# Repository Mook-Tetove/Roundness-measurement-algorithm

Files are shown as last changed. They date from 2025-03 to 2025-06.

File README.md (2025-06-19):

# Roundness-measurement-algorithm
A roundness measurement algorithm program based on single-point laser traversal ranging (based on C language) 
一种基于单点激光遍历测距的圆度测量算法程序（基于C语言）包括软件和硬件模型的设计

这个程序是一个圆度测量系统，它使用激光测距仪和旋转机械臂来获取物体的内外径数据，并通过最小二乘法拟合出一个圆，计算出拟合圆的半径以及测量点的最大、最小半径。以下是该系统的详细说明：
## 系统组成
机械结构
可 360 度旋转的机械臂
固定在机械臂上的激光测距仪
旋转驱动电机（需支持精确角度控制）
##硬件接口
电机控制接口（如步进电机驱动器）
激光测距仪数据采集接口
微控制器或计算机平台运行本程序
##软件功能
控制电机完成 360 度旋转
在每个角度位置采集激光测距数据
计算内径数据
坐标转换与圆拟合算法
计算并输出圆度分析结果
电机控制与数据采集
目前程序中缺少电机控制和自动数据采集部分，以下是需要补充的关键功能：
##电机控制模块
初始化电机驱动器
设置旋转角度分辨率（例如每度一个测量点）
控制电机按指定角度步进旋转
提供角度位置反馈
数据采集流程
1. 初始化系统
2. 设置测量参数（臂长、测量点数等）
3. 将机械臂移动到起始位置
4. 循环360次（每次旋转1度）：
   a. 发送电机旋转命令
   b. 等待电机稳定
   c. 读取激光测距仪数据
   d. 存储当前角度和测量数据
5. 完成测量，回到起始位置
6. 进行数据处理和分析

##使用说明
系统连接
将激光测距仪连接到数据采集接口
将电机驱动器连接到控制接口
确保系统供电稳定
参数设置
修改程序中的测量参数（如测量点数、角度分辨率）
输入机械臂长度（程序中的Rceliangbi）
运行程序
编译并运行程序
程序会提示输入机械臂长度
程序将控制电机旋转并采集数据
最终输出拟合圆半径和测量点的最大 / 最小半径

##注意事项
程序中的 GPIO 引脚定义需要根据实际硬件连接进行修改
步进电机控制参数（如细分数、步进脉冲频率）需要根据实际电机和驱动器调整
激光测距仪数据读取函数需要根据实际设备接口协议实现
电机旋转时需要确保机械结构安全，避免碰撞
在实际应用中，可能需要增加滤波算法处理测量噪声
圆拟合算法中的数学公式可能需要根据具体应用场景调整
以上是该圆度测量系统的详细说明和改进建议。根据实际硬件平台和设备接口，你可能需要进一步修改代码以实现完整功能。

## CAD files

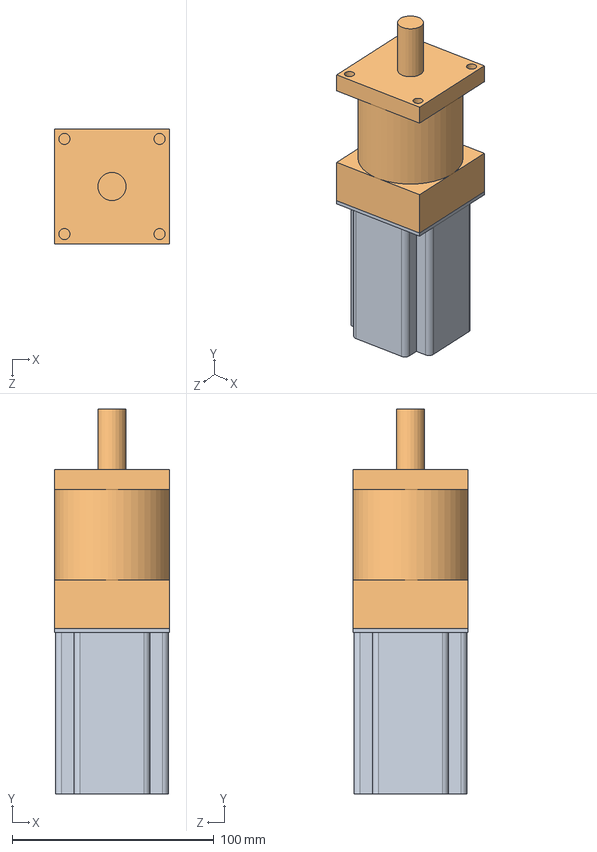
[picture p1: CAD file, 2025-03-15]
Roundness measuring instrument/电子/圆度-57步进减速箱装配.SLDASM
57.0 x 190.8 x 57.0 mm
圆度-标准件-57步进电机-82
圆度-标准件-50减速比减速箱

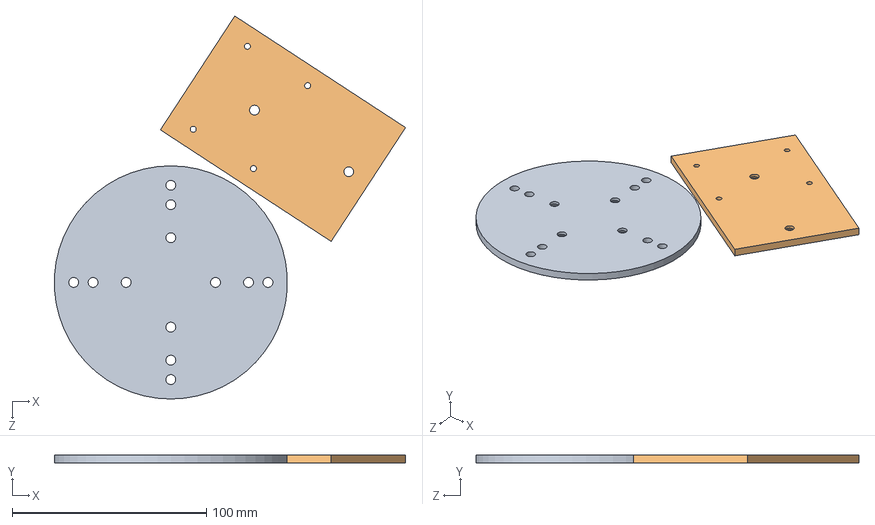
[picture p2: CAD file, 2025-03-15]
Roundness measuring instrument/4.SLDASM
180.7 x 4.00 x 197.1 mm
圆度-4mm玻纤-法兰摇臂转接板
圆度-4mm玻纤-激光测距版

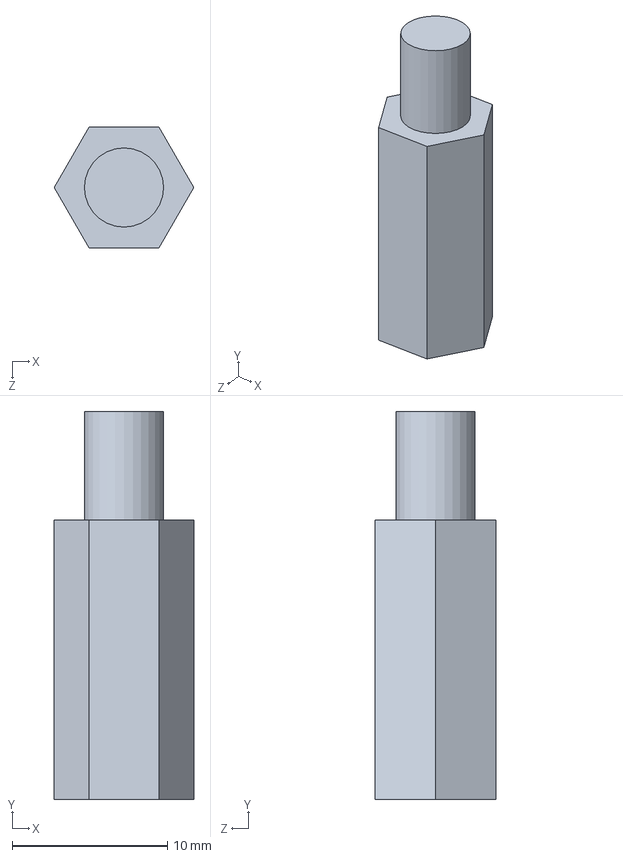
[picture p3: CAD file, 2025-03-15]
Roundness measuring instrument/五金/圆度-标准件-单通铜柱-m5-18-7.SLDPRT
9.00 x 25.0 x 7.79 mm

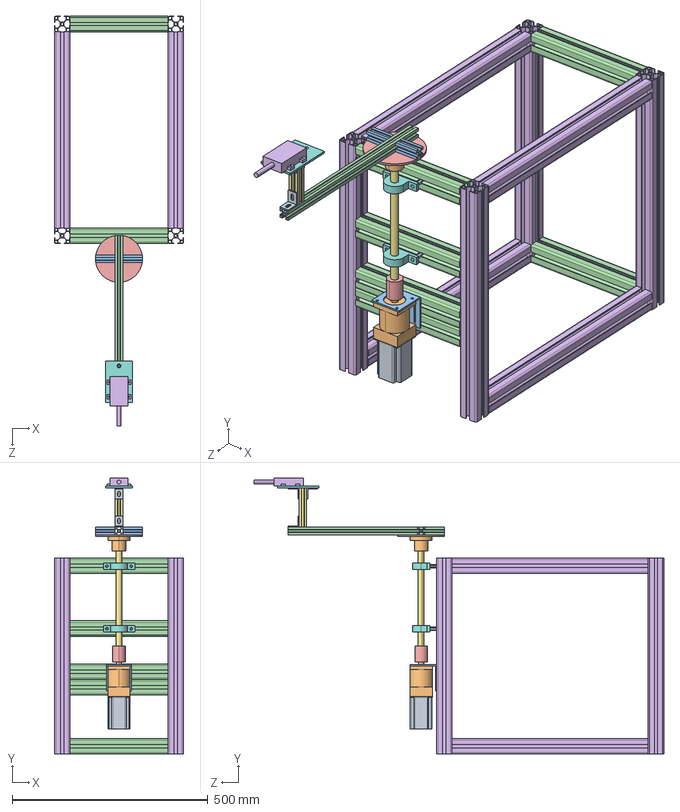
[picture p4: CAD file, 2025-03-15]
Roundness measuring instrument/圆度测量仪.STEP
330.0 x 704.1 x 1045.0 mm
圆度-标准件-57步进电机-82
圆度-标准件-50减速比减速箱
圆度-标准件-57步进电机减速箱支架
圆度-铝型材-4040-200 x 6
圆度-梅花联轴器-14-30-35
圆度-铝型材-4040-500 x 8
圆度-钢杆-15-200
圆度-标准件-立座轴承-15-43-7 x 2
圆度-标准件-单通铜柱-m5-18-7 x 4
圆度-标准件-法兰夹紧联轴器-15-37
圆度-铝型材-2020-50 x 2
圆度-铝型材-2020-500
圆度-4mm玻纤-法兰摇臂转接板
圆度-标准件-激光测距仪
圆度-铝型材-2020-100
圆度-4mm玻纤-激光测距版
圆度-标准件-2020角铁 x 3

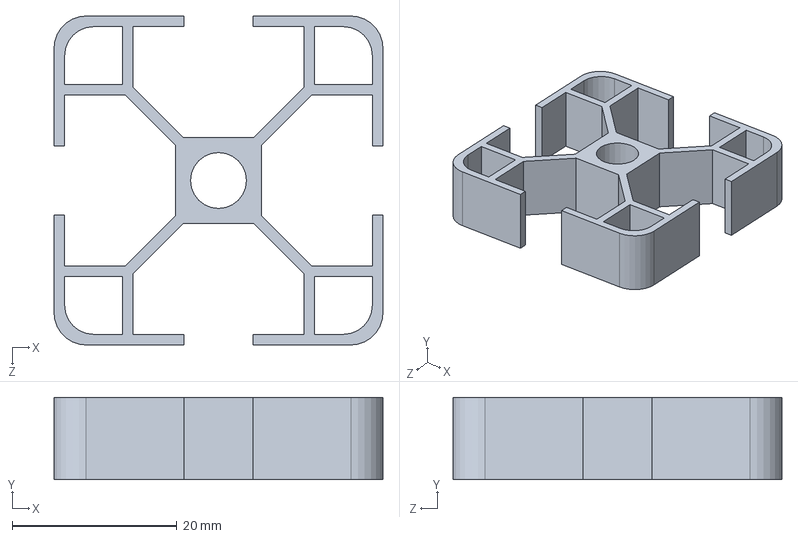
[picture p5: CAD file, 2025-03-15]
Roundness measuring instrument/型材/圆度-铝型材-4040-10.SLDPRT
40.0 x 10.0 x 40.0 mm

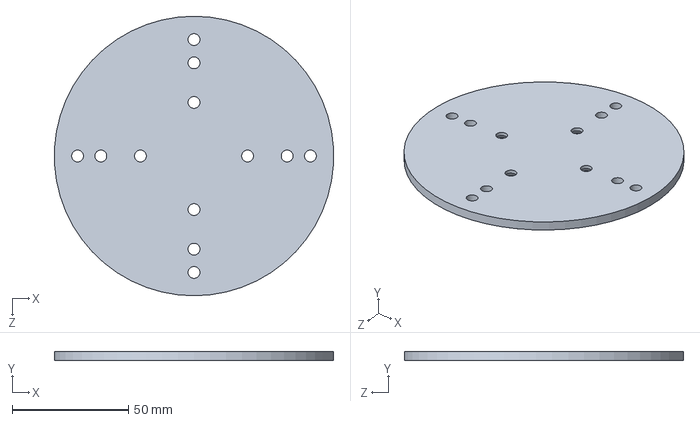
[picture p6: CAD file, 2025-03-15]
Roundness measuring instrument/板件/圆度-4mm玻纤-法兰摇臂转接板.SLDPRT
119.8 x 4.00 x 120.0 mm

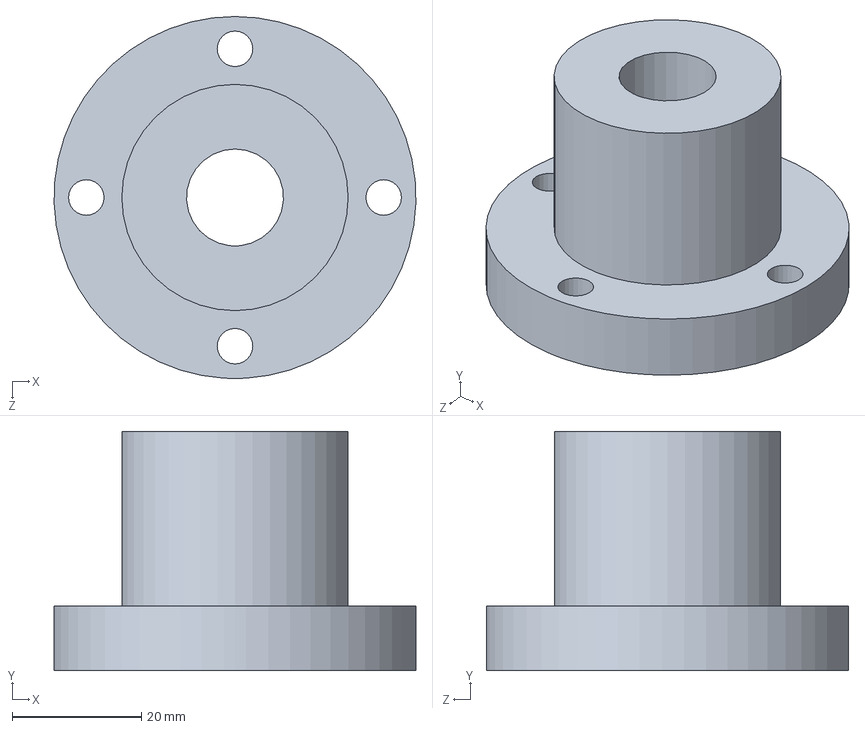
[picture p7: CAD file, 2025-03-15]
Roundness measuring instrument/五金/圆度-标准件-法兰夹紧联轴器-15-37.SLDPRT
56.0 x 37.0 x 56.0 mm

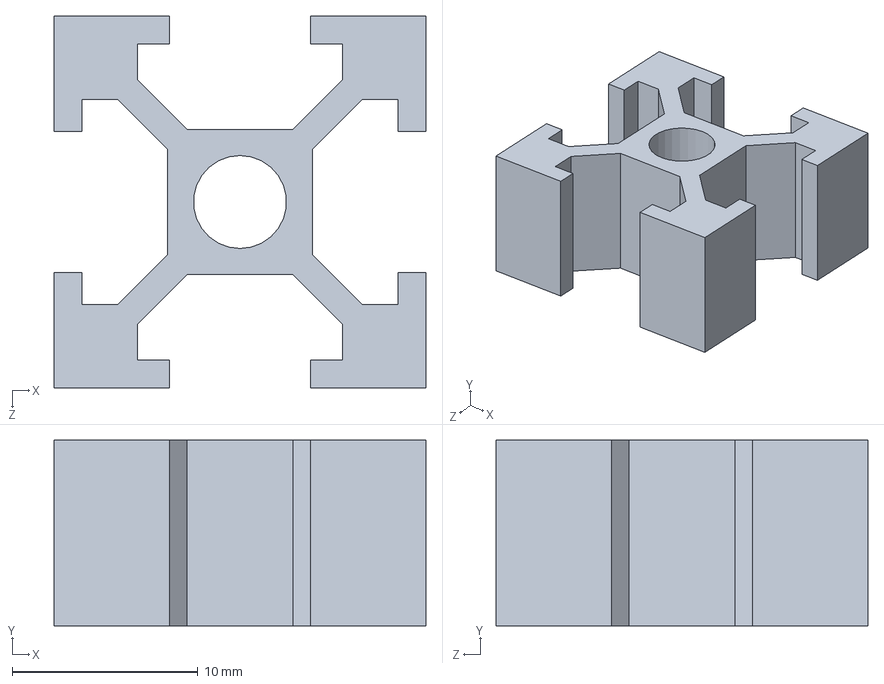
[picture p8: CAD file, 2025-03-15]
Roundness measuring instrument/型材/圆度-铝型材-2020-10.SLDPRT
20.0 x 10.0 x 20.0 mm

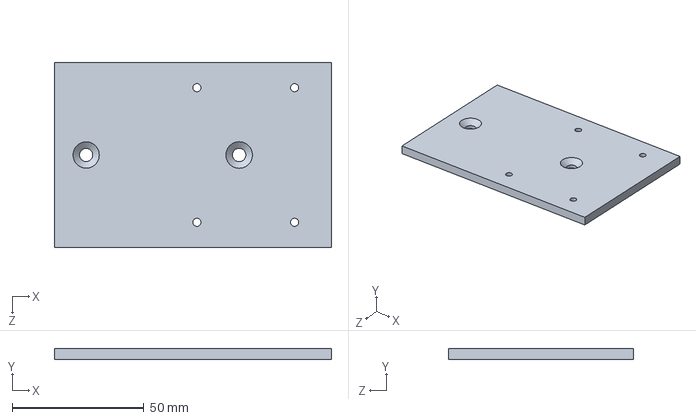
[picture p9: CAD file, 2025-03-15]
Roundness measuring instrument/板件/圆度-4mm玻纤-激光测距版.SLDPRT
105.0 x 4.00 x 70.0 mm

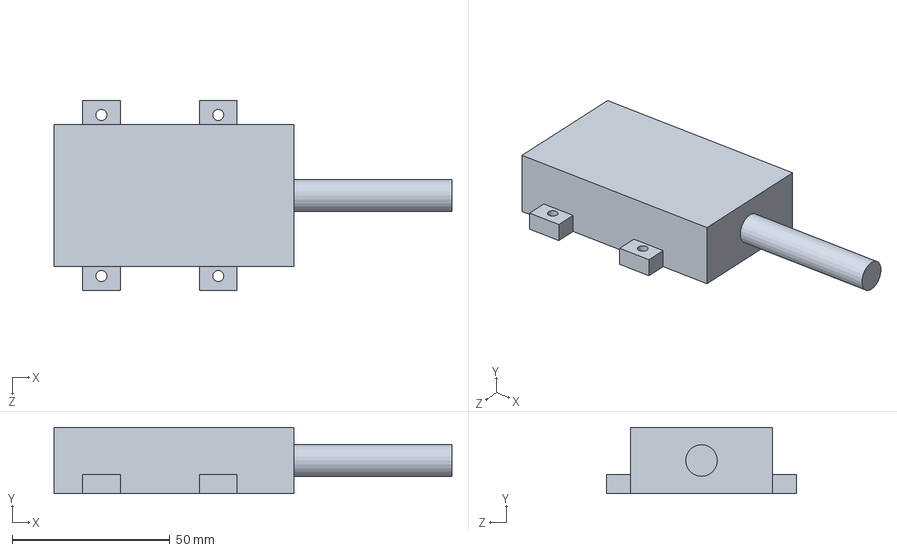
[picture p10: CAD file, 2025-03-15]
Roundness measuring instrument/电子/圆度-标准件-激光测距仪.SLDPRT
126.0 x 21.0 x 60.0 mm

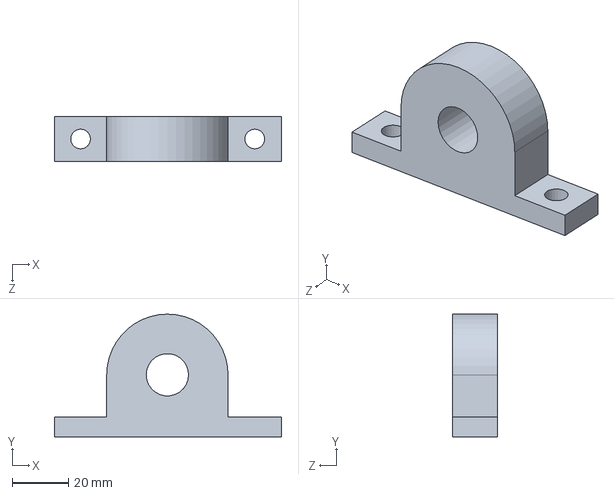
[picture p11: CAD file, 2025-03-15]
Roundness measuring instrument/五金/圆度-标准件-立座轴承-15-43-7.SLDPRT
80.4 x 43.5 x 16.0 mm

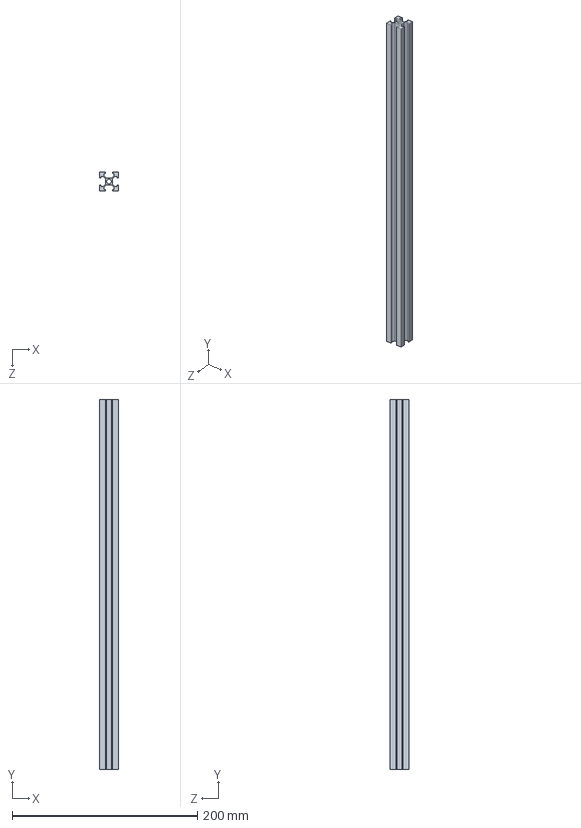
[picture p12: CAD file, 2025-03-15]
Roundness measuring instrument/型材/圆度-铝型材-2020-500.SLDPRT
20.0 x 400.0 x 20.0 mm

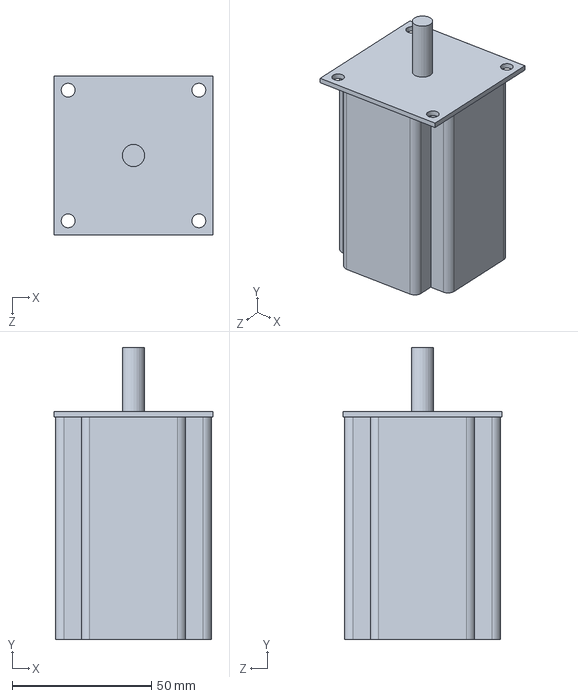
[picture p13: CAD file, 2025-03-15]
Roundness measuring instrument/电子/圆度-标准件-57步进电机-82.SLDPRT
57.0 x 105.0 x 57.0 mm

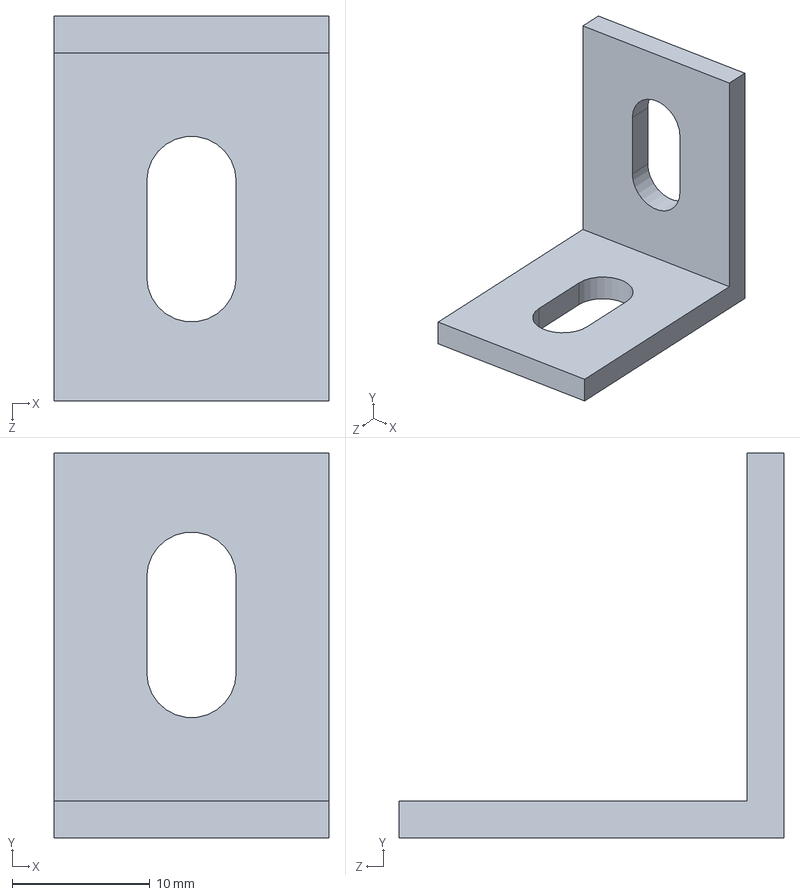
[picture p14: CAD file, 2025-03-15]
Roundness measuring instrument/五金/圆度-标准件-2020角铁.SLDPRT
20.0 x 28.0 x 28.0 mm

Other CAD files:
Roundness measuring instrument/型材/圆度-铝型材-2020-50.SLDPRT
Roundness measuring instrument/电子/圆度-标准件-50减速比减速箱.SLDPRT
Roundness measuring instrument/五金/圆度-标准件-57步进电机减速箱支架.SLDPRT
Roundness measuring instrument/型材/圆度-铝型材-4040-500.SLDPRT
Roundness measuring instrument/4.DWG
Roundness measuring instrument/4.SLDDRW
Roundness measuring instrument/五金/圆度-梅花联轴器-14-30-35.SLDPRT
Roundness measuring instrument/五金/圆度-钢杆-15-200.SLDPRT
Roundness measuring instrument/圆度测量仪.SLDASM
Roundness measuring instrument/型材/圆度-铝型材-2020-100.SLDPRT
Roundness measuring instrument/型材/圆度-铝型材-4040-200.SLDPRT

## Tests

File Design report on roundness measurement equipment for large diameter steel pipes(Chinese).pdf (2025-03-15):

## 大口径钢管圆度测量设备（系统）设计报告

1、技术参数与要求：

钢管外径：Φ508～Φ1422mm;
长度：1.0m～3.0m;
椭圆度测量精度:±1mm;
外周长测量精度:土 1mm;
测量速度≤2 分钟/每圈；
采样密度：360 个采样点/每圈。
2、设备工作性能：

连续工作时间：>8h;
平均无故障时间：>24h。
3、设备工作环境要求：

工作温度：10℃~80℃;
工作电压：220V;
工作湿度：20%~60%。
4、测量系统的基本要求：

①较高的自动化程度，减少因为因素产生的影响。
②采用电脑进行误差分析，减少因为人的失误导致的误差，提升检测系统 的误差分析的可靠性。
③检测系统的选择的硬件应易于维护以及功能更新。
④软件制作简洁明了，可根据不同的检测要求灵便选择检测方案。 ⑤一次可对被测对象的多个几何参数同时进行检测，得到被测工件外部轮 廓尺寸;

⑥尽可能的降低制造成本以及维护费用。
5、系统设计(模块)说明：

测量系统主要分为三大模块：数据采集模块、运动控制模块和计算机数据 处理模块。系统结构如下图所示。

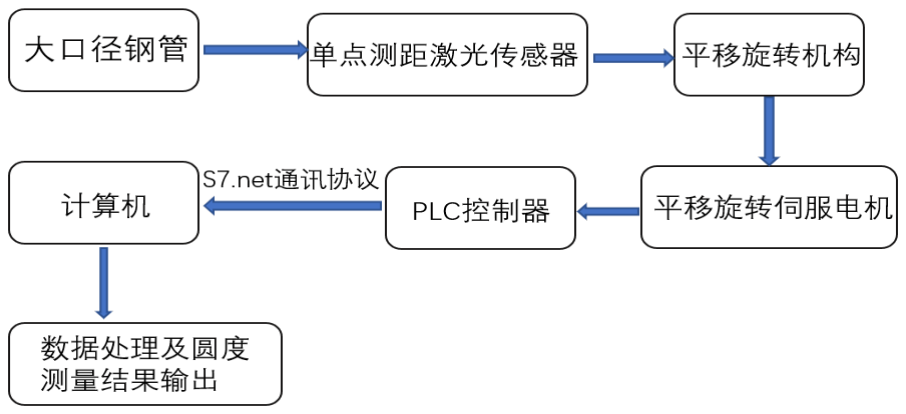
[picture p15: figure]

一、数据采集模块

数据采集模块由减速机、伺服电机及编码器、直线导轨、单点激光测距传 感器组成。它的功能是：固定单点激光测距传感器，并按照一定的速度旋转， 对被测钢管进行圆周遍历测量。详细分为以下几个部分：
（1）减速机：减速机是本测量系统的重要硬件组成部分，它不但可以降低 转速、提高输出扭矩还可以降低负载的惯性。本项目的测量系统选用亿星科技 公司 FLF57-50SW 行星减速机，该减速机具有独特多段减速比，高效率输出扭 力，专利内齿环设计，确保运行时低噪音，密闭式全油封设计确保润滑油脂不 会泄漏，低耗损精密齿轮设计传动效率高速 95%，同时还具有结构紧凑、使用 寿命长、额定输出转矩大、回程间隙小、精度较高等优点。 （2）伺服电机及其驱动器：整个测量系统的动力全来源于电机，电机的选 择在系统中占有重要的位置，它与测量系统的运动能力和稳定性有很大的关 系。在查阅国内外一些关于运动控制技术的资料后，在一定层度上了解了对其 发展现状、实现方案和实际的应用情况。闭环控制系统拥有较高的控制精度和 较强的抑制干扰能力，是运动控制最佳的选择。伺服电机（servo motor)是指 在伺服系统中控制机械元件运转的发动机，是一种补助马达间接变速装置，具 有低频特性好、速度响应快、控制精度高、过载能力强等性能，可根据电压使 控制速度，位置精度非常高，可以将电压信号转化为转矩以及转速以驱动被控 对象。本系统选用的是张大头的 57 步进电机驱动器以及配套的 57 步进电机。 （3）旋转测量臂：由于在实际生产中被测钢管的外径的特殊要求以及对精 度要求较高，现存的位移传感器很难同时满足精度和范围的要求，需要外接测 量臂，所以直线导轨的作用是：支撑和引导激光位移传感器沿着旋转方向平稳 做往复旋转运动，使其移动到合适的位置，以便于激光位移传感器测得的数据 在其测量量程范围内在旋转机构旋转过程中不会碰到钢管内壁；同时还起着充 当测量臂的作用。
（4）传感器固定设备：传感器固定设备用于固定和安装单点激光测距传感 器，使单点激光测距传感器垂直射向转台中轴线方向射到钢管外管壁上，避免 在测量过程中由于传感器安装不稳和偏心而产生测量误差。 二、运动控制模块
运动控制模块由 PLC、伺服电机及其驱动器组成。它的功能是：首先带动 单点激光测距传感器沿中轴线旋转，根据具体测量要求，选择适合的旋转速度

以及采样频率，从而实现自动检测的要求；其次是寻找零位运动控制模块消除 减速机齿轮间隙对测量系统精度的影响。详细分为以下几个部分： a．圆周遍历测量步长和速度控制子系统设计
根据项目的技术条件要求，测量设备圆周遍历一周测量点数为 360 个点， 测量一根钢管耗时不得超过二分钟。
圆周遍历测量总的采集点数决定着伺服电机每转一圈编码器发出的脉冲 数，使用减速比 50:1 的减速机，整个旋转机构遍历一周钢管外端面共遍历 360 点,即旋转机构的测量步长为 1 度，满足测量点数的要求。 速度控制即伺服电机的速度控制也是，包括圆周遍历测量速度控制。本项 目选用松下伺服电机，其驱动器只带 3 位速度设定端（000 到 111）可以设定 8 个不同速度。速度设定值为正时正转，相反设定值为负时反转。由 PLC 直接控 制，最终形成 PLC 控制伺服电机的转速。伺服电机在高速旋转时，突然停止时 容易发生“过冲现象”，产生原因是伺服电机的速度由运行速度突然变为零， 受惯性的影响，旋转机构并不会马上停止，有向前的过冲过程。过冲容易引起 测量设备振动和机械噪声，影响系统的测量精度，甚至使测量设备报废。为了 保证系统运行过程平稳，工作可靠，必须严格控制伺服电机的速度。本系统采 用低速启动，高速测量，低速停止，这样测量系统在一个很低的速度下停止， 很好的抑制了伺服电机所产生的“过冲现象”。
b．消除减速机回程误差对系统精度的影响控制子系统设计 为了确保测量的准确性和一致性，每次测量需从同一个测量起点开始测 量，因此本系统设计一个旋转限位装置，该限位转装置由两个齿轮，一个拨杆 和四个限位开关组成。四个限位开关分别
是逆限位开关、超限位开关、顺限位开关
和零位限位开关，前三个限位开关主要起
着安全保护作用，当大齿轮上拔杆撞到前
面三个中任何一个限位开关触点时，强制
切断整个测量系统的电源；零位限位开关
的作用是确保每次测量时从此点开始测
量，该限位的位置称为零位位置。
如果整个测量系统完成一次测量后，

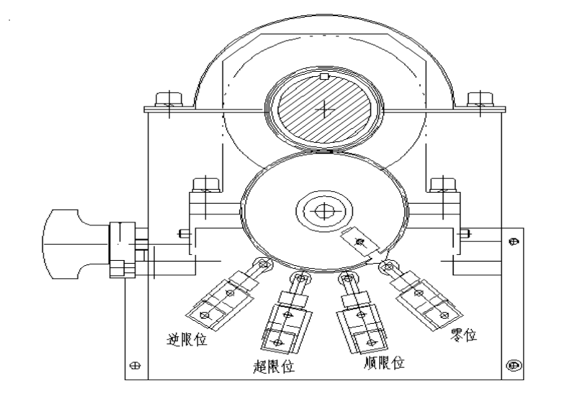
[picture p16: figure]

回到零位时，不做任何处理，系统进行下次测量时减速机齿轮的回程间隙必然 影响系统的测量精度。这是因为减速机由一系列的齿轮构成，减速机的运动可 以简化为一系列齿轮的综合运动。当主动轮正转时，即第一齿轮逆时针旋转， 第一齿轮和第二齿轮的一个齿轮啮合，但是不能和另一面的那个齿轮啮合，所 以当主动轮旋转方向改变时，第二齿轮要和第一齿轮啮合上，第二齿轮必须走 过标记的回程间隙。
三、传感器数据采集子系统设计
本项目设计的传感器数据采集子系统由 PLC、以太网、单点激光测距传感 器和其控制器组成，它的功能是对整个大口径钢管外圆周端面进行圆周遍历等 角度数据采集，并将采集到的数据通过以太网传送给 PLC，最后通过 PLC 把采 样数据传输给计算机数据处理系统进行综合处理。
单点激光测距传感器是传感器数据采集子系统的核心部分，也是测量系统 实现自动测量和控制的首要因素，必须首先确保单点激光测距传感器对被测钢 管圆周信息的采集精度，如果所采集的原始测量精度无法达到足够高的精度，

那么测量系统就无法实现高精度的测量。因此，选择适合本系统的单点激光测 距传感器是非常重要的一个环节。
a. 单点激光测距传感器
单点激光测距传感器具有高精度、高效率、高可靠性等特点，被广泛应用 于精密零件的几何尺寸检测中。
本项目从单点激光测距传感器的测量精度、测量范围、采样频率、光斑直 径、抗干扰能力、温度特性以及经济成本等方面进行综合考虑，最终选择摩天 公司高精确 CCD 激光测距传感器。
利用 CCD 作为接收光线的元件。目标物体反射的光线穿过接收器的透镜， 接收器的透镜将光线聚焦在 PSD 或 CCD 上。PSD 型传感器利用 PSD 上的所有射 束光点之光量分布来决定射束光点的中心，并由此判定目标位置。但是，光量 分布会受目标物体的表面状况影响，造成测量值的变动。CCD 检测射束光点之 光量分布峰值处的像素，并将此判定为目标位置。所以，无论射束光点之光量 如何分布，CCD 均能获得稳定且高精度的结果。
b.单点激光测距传感器的通讯
本文选择摩天 L1S-40 单点激光测距传感器控制器。根据测量的要求，选择 RS232 的通讯方式，实现 PLC 与单点激光测距传感器的通讯。 c.圆周遍历等步长数据采集
单点激光测距传感器固定于旋转测量本体的直线导轨上，并随旋转机构一 起旋转，对钢管端面进行圆周遍历等步长数据采集，如何保证测量步长的准确 性是本项目的重点。
伺服电机编码器用来反馈旋转的角度（位置）给伺服驱动器，伺服驱动器 收到反馈信号后控制伺服电机旋转。设定伺服电机控制器参数即可实现伺服电 机每转一定角度，编码器就会相应的发出一个脉冲，电机持续旋转即可得到周 期一定的脉冲。所以只要能准确的采集到编码器发出的脉冲即可实现圆周遍历 等步长数据采集，同时可以根据此脉冲的数量判断旋转机构是否旋转完一整 圈，减速机的减速比为 50:1，伺服电机每转一圈编码器发出一个脉冲，那么伺 服电机每转过 50 圈，旋转测量装置则转过一圈。为了使 PLC 准确获取采样点 数据，本项目采用了角度触发机制完成测量数据采样。

四、计算机数据处理模块
为了让企业及时地发现并剔除不合格的钢管，所以计算机数据处理的准确 性在本测量系统中起到至关重要的作用。本项目设计的数据处理程序是在.net 平台上开发的。.net 平台是一个面向对象的可视化集成开发环境（IDE），可以

### 进行快速应用程序开发 RAD(Rapid Application Development)；同时.net 平台使用

了 Microsoft Windows 图形用户界面的许多先进特性和设计思想，采用了弹性 可重复利用的完整的面向对象程序语言 C#，基于 C#的应用程序具有速度快，可 重复使用组件的优点。

### 数据处理模块由 s7.net 组件，最小二乘拟合算法和 Microsoft SQL server

2014 数据库组成。其中 s7.net 组件用于 PLC 通讯，获取采样数据；最小二乘拟 合算法用于计算钢管圆心，并由此计算圆周上每一点对应的直径，从而得到最 大最小直径，进一步获取钢管圆度；Microsoft SQL server 2014 数据库用于保存 与钢管圆度相关的数据。

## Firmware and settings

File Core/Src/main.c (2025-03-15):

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
/* Includes ------------------------------------------------------------------*/
#include "main.h"
#include "usart.h"
#include "gpio.h"

/* USER CODE BEGIN Includes */
#include <stdbool.h>
#include "57.h"
#include <stdio.h>
#include <math.h>
/* USER CODE END Includes */

/* USER CODE BEGIN PTD */
__IO bool rxFrameFlag = false;
uint8_t step[13]={0x01,0xFD,0x00,0x03,0xE8,0xB0,0x00,0x00,0x00,0x00,0x01,0x00,0x6B};
uint8_t mea[5]={0xA5,0x5A,0x04,0x00,0xFB};
uint8_t out[15]={0xAB,0xBA,0x00,0x7c,0x00,0x80,0x00,0x73,0x00,0xF3};
uint8_t Angle1[10],n1=10,d,RX01,rou[360];
int angle=0,i=0;
int R,Rmax,Rmin,Routside[360];
#define pi 3.141592
     float Rceliangbi=250;
     float Rinside[360];
     float x[360],y[360];
     float Rpoint[360];
     float Rlixiang;
     float A0=0,A1=0,B0=0,B1=0,C0=0,C1=0,C2=0,D0=0,E0=0,E1=0;
     float A=0,B=0,C=0,D=0,E=0;
     float Aw=0,Bw=0,Cw=0,Dw=0,Ew=0;
    float a,b,c,e;
     float Ox,Oy;
/* USER CODE END PTD */


void SystemClock_Config(void);
/* USER CODE BEGIN 0 */
void test()

{

}
/* USER CODE END 0 */

/**
  * @brief  The application entry point.
  * @retval int
  */
int main(void)
{
  /* MCU Configuration--------------------------------------------------------*/

  /* Reset of all peripherals, Initializes the Flash interface and the Systick. */
  HAL_Init();

  /* Configure the system clock */
  SystemClock_Config();

  /* Initialize all configured peripherals */
  MX_GPIO_Init();
  MX_USART2_UART_Init();
  MX_USART1_UART_Init();
  MX_USART3_UART_Init();
  /* USER CODE BEGIN 2 */
  HAL_Delay(2000);
	HAL_UART_Transmit(&huart2,(uint8_t *)step,13,HAL_MAX_DELAY);

	HAL_Delay(500);
	HAL_UART_Transmit(&huart1,(uint8_t *)mea,5,HAL_MAX_DELAY);
		HAL_Delay(500);
	HAL_UART_Receive_IT(&huart1,&RX01,1); 
	HAL_Delay(5000);
	
	for (i=1;i<=360;i++)
	{
		angle=27.7*i;
		
		
		
		step[6]=(angle >> 24); 
		step[7]=(angle >> 16); 
		step[8]=(angle >> 8); 
		step[9]=(angle >> 0); 
		HAL_UART_Transmit(&huart2,(uint8_t *)step,13,HAL_MAX_DELAY);
		
		HAL_Delay(500);
		Routside[i-1]=d;
	}

  
         for(i=0;i<360;i++) 
         {
           Rinside[i]=Rceliangbi-Routside[i];
           x[i]=Rinside[i]*cos(i*pi/180);
           y[i]=Rinside[i]*sin(i*pi/180);
        }
        
        int k;
        for(k=0;k<360;k++)
        {
          A0=A0+x[k]*x[k];
          A1=A1+x[k];
          B0=B0+x[k]*y[k];
          B1=B1+y[k];
          C0=C0+x[k]*x[k]*x[k];
          C1=C1+x[k]*y[k]*y[k];
          C2=C2+x[k]*x[k]+y[k]*y[k];
          D0=D0+y[k]*y[k];
          E0=E0+x[k]*x[k]*y[k];
          E1=E1+y[k]*y[k]*y[k];
        }

          Aw=360*A0;
          Bw=360*B0;
          Cw=360*C0+360*C1;
          Dw=360*D0;
          Ew=360*E0+360*E1;

          A=Aw-A1*A1;
          B=Bw-A1*B1;
          C=Cw-C2*A1;
          D=Dw+B1*B1;
          E=Ew+C2*B1;

             a=(B*E-C*D)/(A*D-B*B);
             b=(A*E-B*C)/(A*D-B*B);
             c=-(C2+a*A1+b*B1)/360;
    
      Ox=-a/2;
      Oy=-b/2;
      d=a*a/4;
      e=b*b/4;
      R=sqrt((a*a/4)-(b*b/4)-c);

      int j;
      for(j=0;j<360;j++)
      {
        Rpoint[j]=sqrt((x[j]-Ox)*(x[j]-Ox)+(y[j]-Oy)*(y[j]-Oy));
      }

      int n;
      Rmax=Rmin=Rpoint[0];
      for(n=1;n<360;n++)
      {
        if(Rpoint[n]>Rmax)
        {
          Rmax=Rpoint[n];
        }
        if(Rpoint[n]<Rmin)
        {
          Rmin=Rpoint[n];
        }
      }

			
  /* USER CODE END 2 */

  /* Infinite loop */
  /* USER CODE BEGIN WHILE */
  while (1)
  {
//HAL_Delay(200);
//HAL_UART_Transmit(&huart3,(uint8_t *)out,15,HAL_MAX_DELAY);
		
    /* USER CODE END WHILE */

    /* USER CODE BEGIN 3 */
  }
  /* USER CODE END 3 */
}

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
/* USER CODE BEGIN 4 */
 void HAL_UART_RxCpltCallback(UART_HandleTypeDef *huart)
{
 if(huart== &huart1) 
 {
    if((RX01==0xB4)&&(n1>8))  //判断帧头
	  {
   		n1=0;
  	}
  	if(n1<8)//有几位就接收几位，从零开始
  	{
	    Angle1[n1]=RX01;
	  	n1++;
	  }
	  if(n1==8)
  	{	
			
	  d=(Angle1[5]<<8)|Angle1[6];
    	   n1++;             
    }
  	HAL_UART_Receive_IT(&huart1,&RX01,5); 
	}
  
}

/* USER CODE END 4 */
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


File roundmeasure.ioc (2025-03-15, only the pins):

Mcu.UserName=STM32F103C8Tx
PA10.Signal=USART1_RX
PA13.Signal=SYS_JTMS-SWDIO
PA14.Signal=SYS_JTCK-SWCLK
PA2.Signal=USART2_TX
PA3.Signal=USART2_RX
PA9.Signal=USART1_TX
PB10.Signal=USART3_TX
PB11.Signal=USART3_RX
PD0-OSC_IN.Signal=RCC_OSC_IN
PD1-OSC_OUT.Signal=RCC_OSC_OUT

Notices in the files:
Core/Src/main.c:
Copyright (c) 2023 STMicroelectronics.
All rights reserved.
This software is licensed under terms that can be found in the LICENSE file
